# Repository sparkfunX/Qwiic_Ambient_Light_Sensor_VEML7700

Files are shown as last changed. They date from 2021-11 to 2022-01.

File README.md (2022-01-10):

SparkX Ambient Light Sensor - VEML7700 (Qwiic)
========================================

SparkX Ambient Light Sensor - VEML7700 (Qwiic) (SPX-18981) (https://www.sparkfun.com/products/18981)

[*SparkX Ambient Light Sensor - VEML7700 (Qwiic) (SPX-18981)*](https://www.sparkfun.com/products/18981)

The VEML7700 is a high accuracy, 16-bit resolution, digital ambient light sensor in a miniature transparent 6.8 mm x 3.0 mm x 2.5 mm package.
It includes a high sensitivity photodiode, a low noise amplifier, a 16-bit A/D converter and supports an easy to use I<sup>2</sup>C bus communication interface.

* Filtron<sup>TM</sup> technology adaption: close to real human eye response
* O-Trim<sup>TM</sup> technology adoption: ALS output tolerance ≤ 10 %
* 16-bit dynamic range for ambient light detection from 0 lx to about 167 klx with resolution down to 0.005 lx/count
* 100 Hz and 120 Hz flicker noise rejection
* Excellent temperature compensation
* High dynamic detection resolution
* Software shutdown mode control
* High and low threshold windows with interrupt flags

Our [Arduino Library](https://github.com/sparkfun/SparkFun_VEML7700_Arduino_Library) converts the raw sensor data into lux,
automatically compensating for the sensor's gain and integration time settings.

Repository Contents
-------------------

- [**/Documents**](./Documents) - datasheets etc.
- [**/Hardware**](./Hardware) - Eagle PCB, SCH and LBR design files
- [**LICENSE.md**](./LICENSE.md) - contains the licence information

Documentation
--------------

* **[SparkFun VEML7700 Arduino Library](https://github.com/sparkfun/SparkFun_VEML7700_Arduino_Library)** - Arduino library for the ambient light sensor - VEML7700.

Product Versions
----------------

* [SPX-18981](https://www.sparkfun.com/products/18981) - Original SparkX Release.

License Information
-------------------

This product is _**open source**_!

Please review the LICENSE.md file for license information.

If you have any questions or concerns on licensing, please contact technical support on our [SparkFun forums](https://forum.sparkfun.com/viewforum.php?f=152).

Distributed as-is; no warranty is given.

- Your friends at SparkFun.

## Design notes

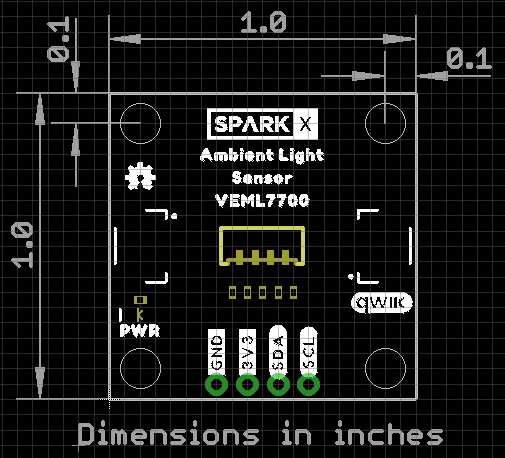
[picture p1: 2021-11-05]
Hardware/Dimensions.jpg

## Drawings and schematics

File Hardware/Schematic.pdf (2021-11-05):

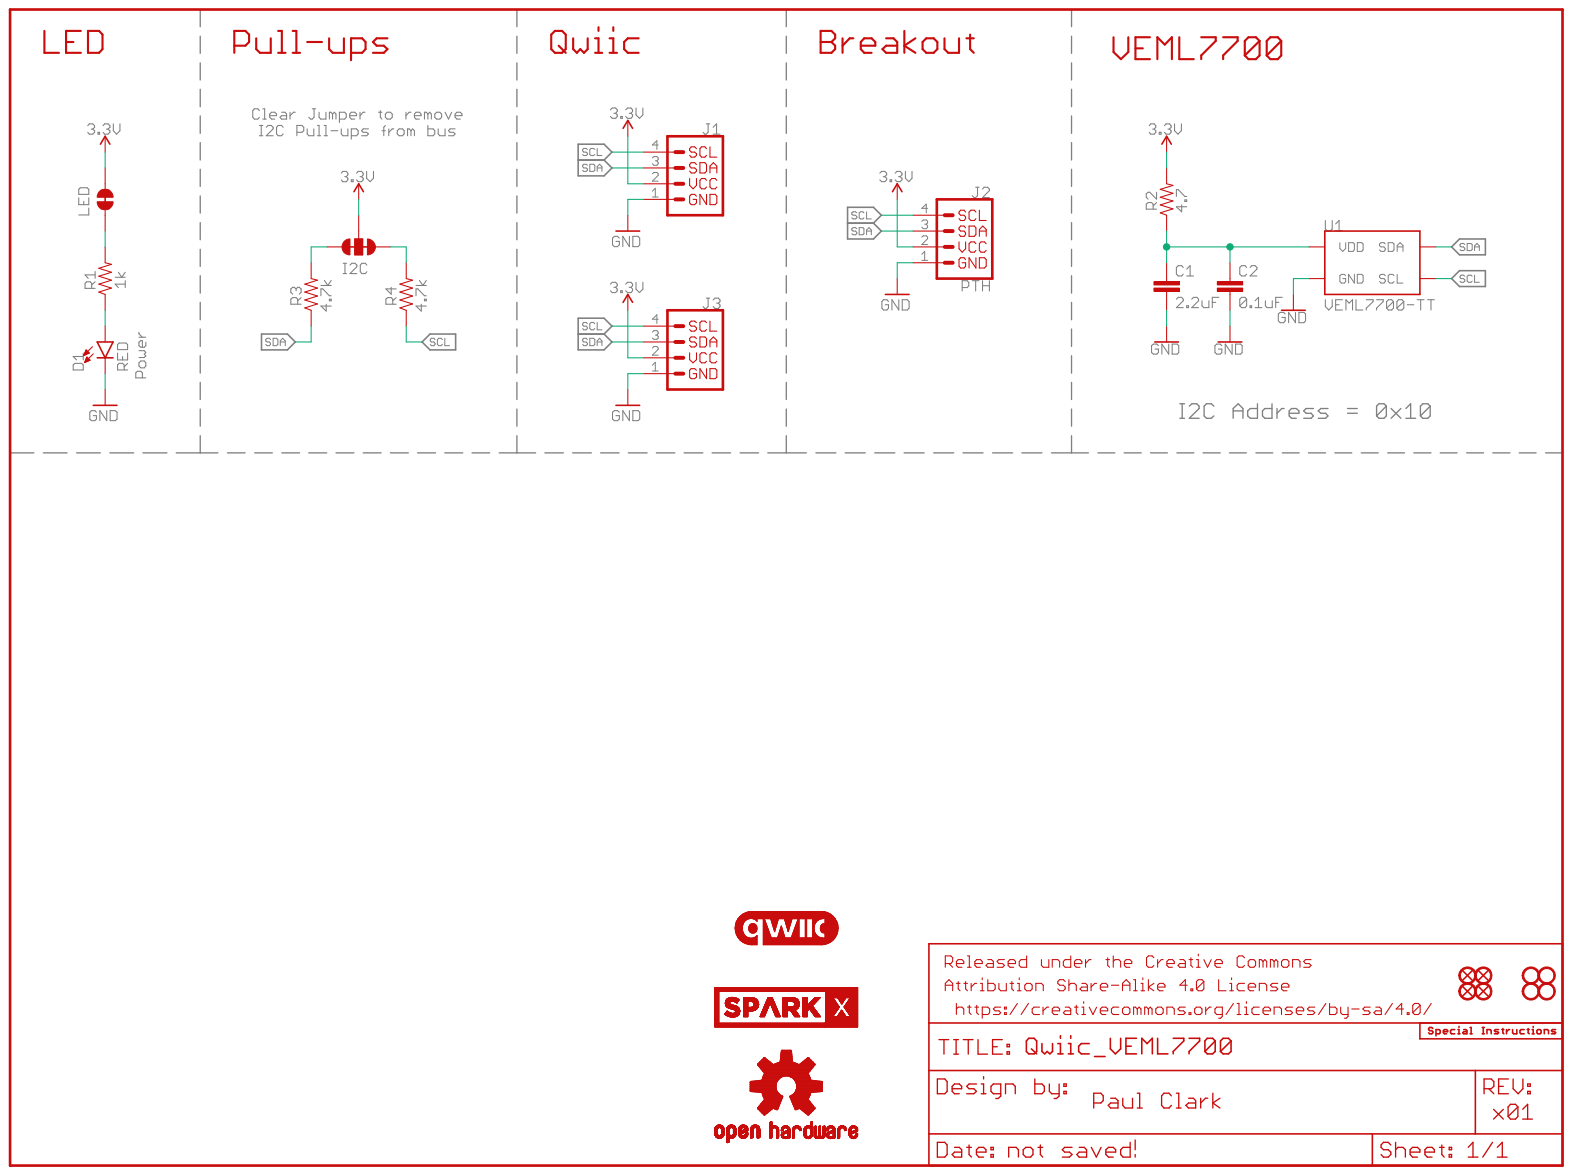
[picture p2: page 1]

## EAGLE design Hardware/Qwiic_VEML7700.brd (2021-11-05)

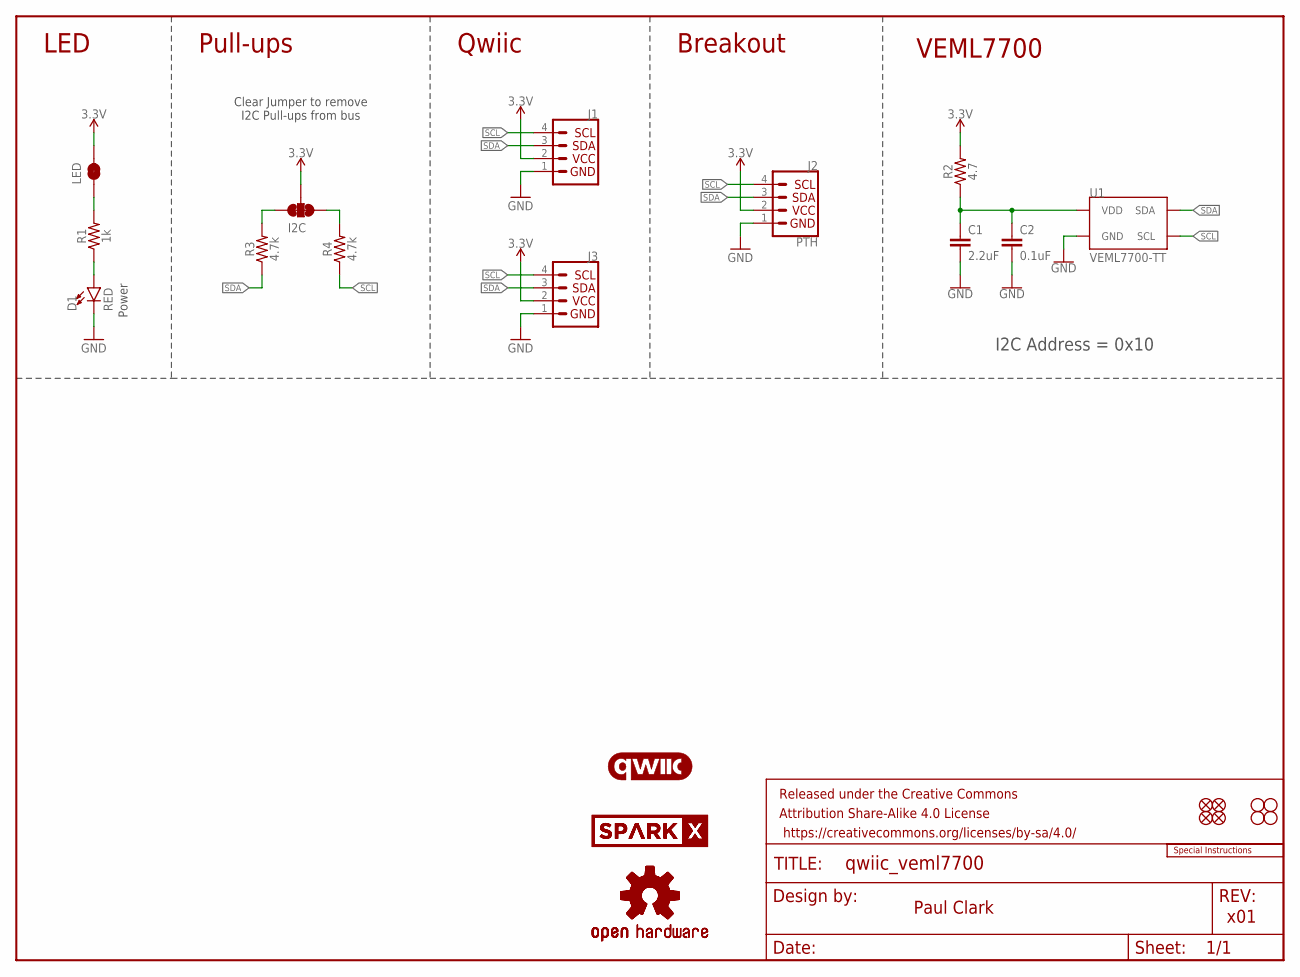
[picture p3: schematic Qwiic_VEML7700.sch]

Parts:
C1: 2.2uF; 0402-TIGHT
C2: 0.1uF; 0402-TIGHT
D1: RED; LED-0603
FRAME1: FRAME-LETTER; CREATIVE_COMMONS
I2C: JUMPER-SMT_3_2-NC_TRACE_SILK; SMT-JUMPER_3_2-NC_TRACE_SILK
J1, J3: Qwiic Right Angle; JST04_1MM_RA
J2: PTH; 1X04_NO_SILK
JP1, JP2, JP5, JP6: FIDUCIAL1X2; FIDUCIAL-1X2
JP3, JP4, JP7, JP8: STAND-OFF
LED: JUMPER-SMT_2_NC_TRACE_SILK; SMT-JUMPER_2_NC_TRACE_SILK
LOGO1, LOGO4: OSHW-LOGOMINI; OSHW-LOGO-MINI
LOGO2: SPECIAL_INSTRUCTIONS-ORDERING; ORDERING_INSTRUCTIONS
LOGO3: QWIIC_LOGO_5MM; QWIIC_5MM
R1: 1k; 0402-TIGHT
R2: 4.7; 0402-TIGHT
R3, R4: 4.7k; 0402-TIGHT
U1: VEML7700-TT; VEML7700_TT
U$2, U$21: SPARKX-LOGO4; SPARKX-MEDIUM

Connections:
3.3V: I2C.2, J1.2, J2.2, J3.2, LED.2, R2.2
GND: C1.2, C2.2, D1.C, J1.1, J2.1, J3.1, U1.3 (GND)
unnamed: I2C.1, R4.2
unnamed: I2C.3, R3.2
unnamed: D1.A, R1.1
unnamed: LED.1, R1.2
unnamed: C1.1, C2.1, R2.1, U1.2 (VDD)
SCL: J1.4, J2.4, J3.4, R4.1, U1.1 (SCL)
SDA: J1.3, J2.3, J3.3, R3.1, U1.4 (SDA)

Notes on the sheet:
Paul Clark
x01
Clear Jumper to remove I2C Pull-ups from bus
Power
LED
Pull-ups
Qwiic
Breakout
VEML7700
I2C Address = 0x10

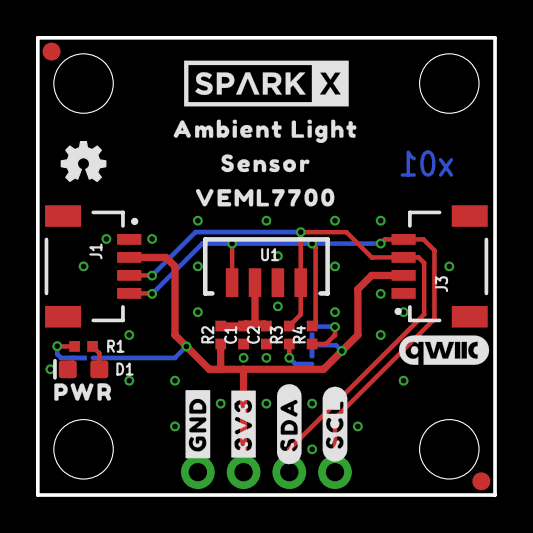
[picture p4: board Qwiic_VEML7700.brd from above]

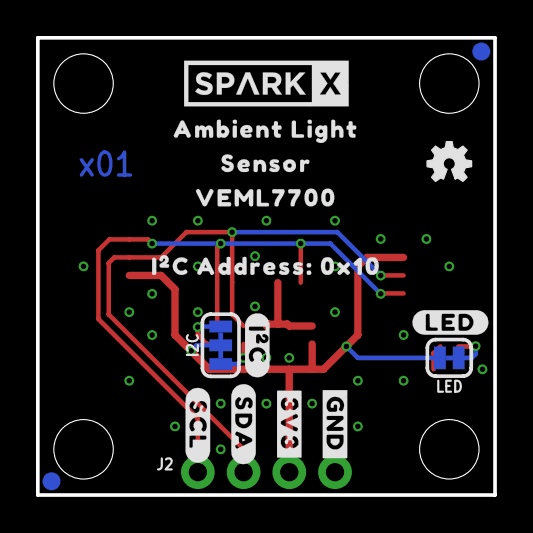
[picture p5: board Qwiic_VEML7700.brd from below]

Board: 2 copper layers, 25.4 x 25.4 mm, 46 parts (17 on the bottom side), 9 nets.

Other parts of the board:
U$1, U$3: #3V3#0
U$4, U$5: #GND#0
U$6, U$7: #SDA#0
U$8, U$9: #SCL#0
U$10: PWR0
U$11, U$12: AMBIENT_LIGHT0
U$13, U$14: SENSOR0
U$15, U$16: VEML77000
U$17: #I�C#0
U$18: I�C_ADDRESS#_0X100
U$19: #LED#0

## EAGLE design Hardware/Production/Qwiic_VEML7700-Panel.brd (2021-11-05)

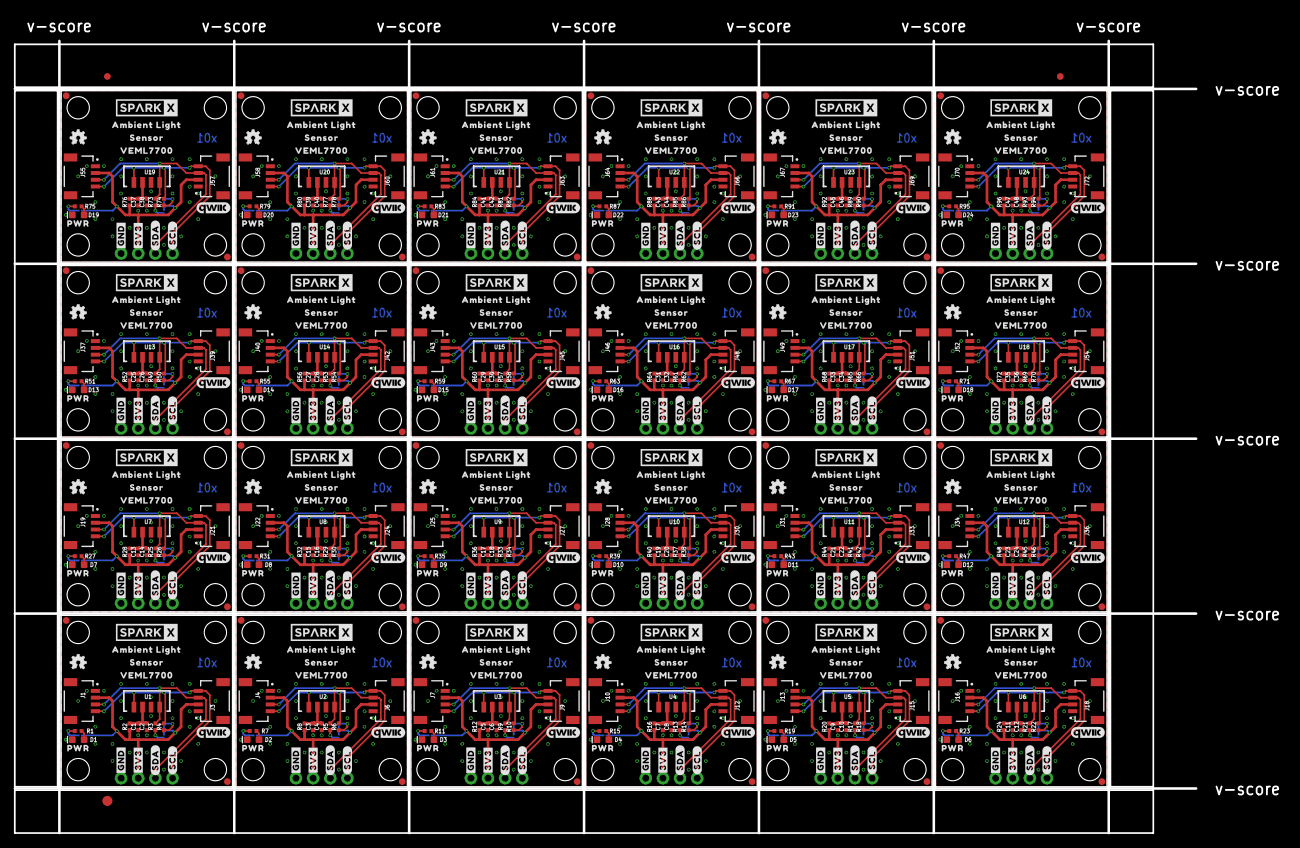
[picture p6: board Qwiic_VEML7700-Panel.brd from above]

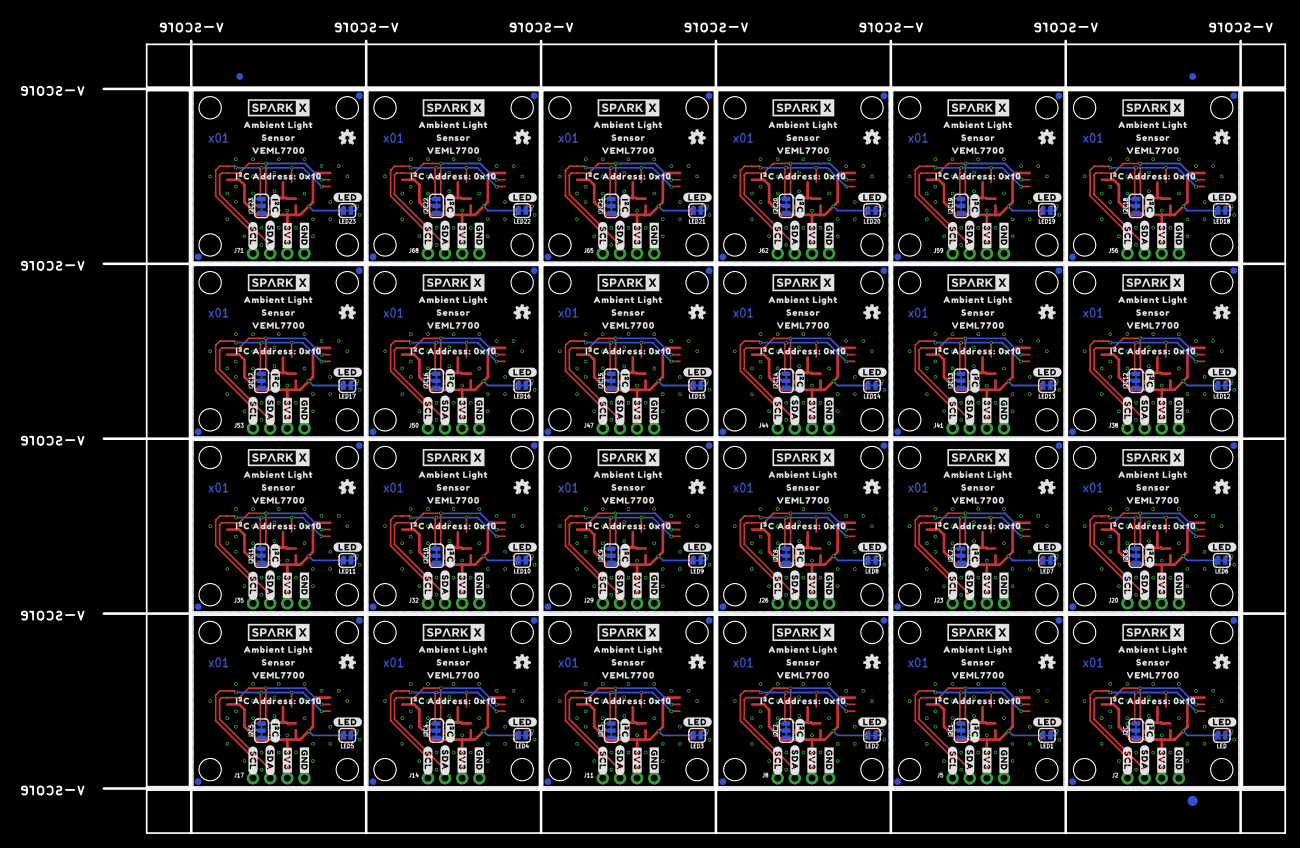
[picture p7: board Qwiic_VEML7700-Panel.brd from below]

Board: 2 copper layers, 175.0 x 117.3 mm, 1062 parts (411 on the bottom side), 216 nets.

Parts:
C1, C3, C5, C7, C9, C11, C13, C15, C17, C19, C21, C23, C25, C27, C29, C31, C33, C35, C37, C39, C41, C43, C45, C47: 2.2uF; 0402-TIGHT
C2, C4, C6, C8, C10, C12, C14, C16, C18, C20, C22, C24, C26, C28, C30, C32, C34, C36, C38, C40, C42, C44, C46, C48: 0.1uF; 0402-TIGHT
D1, D2, D3, D4, D5, D6, D7, D8, D9, D10, D11, D12, D13, D14, D15, D16, D17, D18, D19, D20, D21, D22, D23, D24: RED; LED-0603
E$1, E$2, E$3, E$4: FIDUCIAL-1X2
E$5, E$6: FIDUCIAL-1.5X3
I2C, I2C1, I2C2, I2C3, I2C4, I2C5, I2C6, I2C7, I2C8, I2C9, I2C10, I2C11, I2C12, I2C13, I2C14, I2C15, I2C16, I2C17, I2C18, I2C19, I2C20, I2C21, I2C22, I2C23: JUMPER-SMT_3_2-NC_TRACE_SILK; SMT-JUMPER_3_2-NC_TRACE_SILK
J1, J3, J4, J6, J7, J9, J10, J12, J13, J15, J16, J18, J19, J21, J22, J24, J25, J27, J28, J30, J31, J33, J34, J36, J37, J39, J40, J42, J43, J45, J46, J48, J49, J51, J52, J54, J55, J57, J58, J60, J61, J63, J64, J66, J67, J69, J70, J72: Qwiic Right Angle; JST04_1MM_RA
J2, J5, J8, J11, J14, J17, J20, J23, J26, J29, J32, J35, J38, J41, J44, J47, J50, J53, J56, J59, J62, J65, J68, J71: PTH; 1X04_NO_SILK
JP1, JP2, JP5, JP6, JP11, JP12, JP13, JP14, JP19, JP20, JP21, JP22, JP27, JP28, JP29, JP30, JP35, JP36, JP37, JP38, JP43, JP44, JP45, JP46, JP51, JP52, JP53, JP54, JP59, JP60, JP61, JP62, JP67, JP68, JP69, JP70, JP75, JP76, JP77, JP78, JP83, JP84, JP85, JP86, JP91, JP92, JP93, JP94, JP99, JP100, JP101, JP102, JP107, JP108, JP109, JP110, JP115, JP116, JP117, JP118, JP123, JP124, JP125, JP126, JP131, JP132, JP133, JP134, JP139, JP140, JP141, JP142, JP147, JP148, JP149, JP150, JP155, JP156, JP157, JP158, JP163, JP164, JP165, JP166, JP171, JP172, JP173, JP174, JP179, JP180, JP181, JP182, JP187, JP188, JP189, JP190: FIDUCIAL1X2; FIDUCIAL-1X2
JP3, JP4, JP7, JP8, JP9, JP10, JP15, JP16, JP17, JP18, JP23, JP24, JP25, JP26, JP31, JP32, JP33, JP34, JP39, JP40, JP41, JP42, JP47, JP48, JP49, JP50, JP55, JP56, JP57, JP58, JP63, JP64, JP65, JP66, JP71, JP72, JP73, JP74, JP79, JP80, JP81, JP82, JP87, JP88, JP89, JP90, JP95, JP96, JP97, JP98, JP103, JP104, JP105, JP106, JP111, JP112, JP113, JP114, JP119, JP120, JP121, JP122, JP127, JP128, JP129, JP130, JP135, JP136, JP137, JP138, JP143, JP144, JP145, JP146, JP151, JP152, JP153, JP154, JP159, JP160, JP161, JP162, JP167, JP168, JP169, JP170, JP175, JP176, JP177, JP178, JP183, JP184, JP185, JP186, JP191, JP192: STAND-OFF
LED, LED1, LED2, LED3, LED4, LED5, LED6, LED7, LED8, LED9, LED10, LED11, LED12, LED13, LED14, LED15, LED16, LED17, LED18, LED19, LED20, LED21, LED22, LED23: SMT-JUMPER_2_NC_TRACE_SILK
LOGO1, LOGO2, LOGO4, LOGO6, LOGO7, LOGO9, LOGO10, LOGO12, LOGO13, LOGO15, LOGO16, LOGO18, LOGO19, LOGO21, LOGO22, LOGO24, LOGO25, LOGO27, LOGO28, LOGO30, LOGO31, LOGO33, LOGO34, LOGO36, LOGO37, LOGO39, LOGO40, LOGO42, LOGO43, LOGO45, LOGO46, LOGO48, LOGO49, LOGO51, LOGO52, LOGO54, LOGO55, LOGO57, LOGO58, LOGO60, LOGO61, LOGO63, LOGO64, LOGO66, LOGO67, LOGO69, LOGO70, LOGO72: OSHW-LOGOMINI; OSHW-LOGO-MINI
LOGO3, LOGO5, LOGO8, LOGO11, LOGO14, LOGO17, LOGO20, LOGO23, LOGO26, LOGO29, LOGO32, LOGO35, LOGO38, LOGO41, LOGO44, LOGO47, LOGO50, LOGO53, LOGO56, LOGO59, LOGO62, LOGO65, LOGO68, LOGO71: QWIIC_LOGO_5MM; QWIIC_5MM
R1, R7, R11, R15, R19, R23, R27, R31, R35, R39, R43, R47, R51, R55, R59, R63, R67, R71, R75, R79, R83, R87, R91, R95: 1k; 0402-TIGHT
R2, R8, R12, R16, R20, R24, R28, R32, R36, R40, R44, R48, R52, R56, R60, R64, R68, R72, R76, R80, R84, R88, R92, R96: 4.7; 0402-TIGHT
R3, R4, R5, R6, R9, R10, R13, R14, R17, R18, R21, R22, R25, R26, R29, R30, R33, R34, R37, R38, R41, R42, R45, R46, R49, R50, R53, R54, R57, R58, R61, R62, R65, R66, R69, R70, R73, R74, R77, R78, R81, R82, R85, R86, R89, R90, R93, R94: 4.7k; 0402-TIGHT
U1, U2, U3, U4, U5, U6, U7, U8, U9, U10, U11, U12, U13, U14, U15, U16, U17, U18, U19, U20, U21, U22, U23, U24: VEML7700-TT; VEML7700_TT
U$1, U$3, U$23, U$24, U$43, U$44, U$63, U$64, U$83, U$84, U$103, U$104, U$123, U$124, U$143, U$144, U$163, U$164, U$183, U$184, U$203, U$204, U$223, U$224, U$243, U$244, U$263, U$264, U$283, U$284, U$303, U$304, U$323, U$324, U$343, U$344, U$363, U$364, U$383, U$384, U$403, U$404, U$423, U$424, U$443, U$444, U$463, U$464: #3V3#0
U$2, U$20, U$21, U$22, U$41, U$42, U$61, U$62, U$81, U$82, U$101, U$102, U$121, U$122, U$141, U$142, U$161, U$162, U$181, U$182, U$201, U$202, U$221, U$222, U$241, U$242, U$261, U$262, U$281, U$282, U$301, U$302, U$321, U$322, U$341, U$342, U$361, U$362, U$381, U$382, U$401, U$402, U$421, U$422, U$441, U$442, U$461, U$462: SPARKX-LOGO4; SPARKX-MEDIUM
U$4, U$5, U$25, U$26, U$45, U$46, U$65, U$66, U$85, U$86, U$105, U$106, U$125, U$126, U$145, U$146, U$165, U$166, U$185, U$186, U$205, U$206, U$225, U$226, U$245, U$246, U$265, U$266, U$285, U$286, U$305, U$306, U$325, U$326, U$345, U$346, U$365, U$366, U$385, U$386, U$405, U$406, U$425, U$426, U$445, U$446, U$465, U$466: #GND#0
U$6, U$7, U$27, U$28, U$47, U$48, U$67, U$68, U$87, U$88, U$107, U$108, U$127, U$128, U$147, U$148, U$167, U$168, U$187, U$188, U$207, U$208, U$227, U$228, U$247, U$248, U$267, U$268, U$287, U$288, U$307, U$308, U$327, U$328, U$347, U$348, U$367, U$368, U$387, U$388, U$407, U$408, U$427, U$428, U$447, U$448, U$467, U$468: #SDA#0
U$8, U$9, U$29, U$30, U$49, U$50, U$69, U$70, U$89, U$90, U$109, U$110, U$129, U$130, U$149, U$150, U$169, U$170, U$189, U$190, U$209, U$210, U$229, U$230, U$249, U$250, U$269, U$270, U$289, U$290, U$309, U$310, U$329, U$330, U$349, U$350, U$369, U$370, U$389, U$390, U$409, U$410, U$429, U$430, U$449, U$450, U$469, U$470: #SCL#0
U$10, U$31, U$51, U$71, U$91, U$111, U$131, U$151, U$171, U$191, U$211, U$231, U$251, U$271, U$291, U$311, U$331, U$351, U$371, U$391, U$411, U$431, U$451, U$471: PWR0
U$11, U$12, U$32, U$33, U$52, U$53, U$72, U$73, U$92, U$93, U$112, U$113, U$132, U$133, U$152, U$153, U$172, U$173, U$192, U$193, U$212, U$213, U$232, U$233, U$252, U$253, U$272, U$273, U$292, U$293, U$312, U$313, U$332, U$333, U$352, U$353, U$372, U$373, U$392, U$393, U$412, U$413, U$432, U$433, U$452, U$453, U$472, U$473: AMBIENT_LIGHT0
U$13, U$14, U$34, U$35, U$54, U$55, U$74, U$75, U$94, U$95, U$114, U$115, U$134, U$135, U$154, U$155, U$174, U$175, U$194, U$195, U$214, U$215, U$234, U$235, U$254, U$255, U$274, U$275, U$294, U$295, U$314, U$315, U$334, U$335, U$354, U$355, U$374, U$375, U$394, U$395, U$414, U$415, U$434, U$435, U$454, U$455, U$474, U$475: SENSOR0
U$15, U$16, U$36, U$37, U$56, U$57, U$76, U$77, U$96, U$97, U$116, U$117, U$136, U$137, U$156, U$157, U$176, U$177, U$196, U$197, U$216, U$217, U$236, U$237, U$256, U$257, U$276, U$277, U$296, U$297, U$316, U$317, U$336, U$337, U$356, U$357, U$376, U$377, U$396, U$397, U$416, U$417, U$436, U$437, U$456, U$457, U$476, U$477: VEML77000
U$17, U$38, U$58, U$78, U$98, U$118, U$138, U$158, U$178, U$198, U$218, U$238, U$258, U$278, U$298, U$318, U$338, U$358, U$378, U$398, U$418, U$438, U$458, U$478: #I�C#0
U$18, U$39, U$59, U$79, U$99, U$119, U$139, U$159, U$179, U$199, U$219, U$239, U$259, U$279, U$299, U$319, U$339, U$359, U$379, U$399, U$419, U$439, U$459, U$479: I�C_ADDRESS#_0X100
U$19, U$40, U$60, U$80, U$100, U$120, U$140, U$160, U$180, U$200, U$220, U$240, U$260, U$280, U$300, U$320, U$340, U$360, U$380, U$400, U$420, U$440, U$460, U$480: #LED#0

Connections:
3.3V: I2C.2, J1.2, J2.2, J3.2, LED.2, R2.2
3.3V1: I2C1.2, J4.2, J5.2, J6.2, LED1.2, R8.2
3.3V2: I2C2.2, J7.2, J8.2, J9.2, LED2.2, R12.2
3.3V3: I2C3.2, J10.2, J11.2, J12.2, LED3.2, R16.2
3.3V4: I2C4.2, J13.2, J14.2, J15.2, LED4.2, R20.2
3.3V5: I2C5.2, J16.2, J17.2, J18.2, LED5.2, R24.2
3.3V6: I2C6.2, J19.2, J20.2, J21.2, LED6.2, R28.2
3.3V7: I2C7.2, J22.2, J23.2, J24.2, LED7.2, R32.2
3.3V8: I2C8.2, J25.2, J26.2, J27.2, LED8.2, R36.2
3.3V9: I2C9.2, J28.2, J29.2, J30.2, LED9.2, R40.2
3.3V10: I2C10.2, J31.2, J32.2, J33.2, LED10.2, R44.2
3.3V11: I2C11.2, J34.2, J35.2, J36.2, LED11.2, R48.2
3.3V12: I2C12.2, J37.2, J38.2, J39.2, LED12.2, R52.2
3.3V13: I2C13.2, J40.2, J41.2, J42.2, LED13.2, R56.2
3.3V14: I2C14.2, J43.2, J44.2, J45.2, LED14.2, R60.2
3.3V15: I2C15.2, J46.2, J47.2, J48.2, LED15.2, R64.2
3.3V16: I2C16.2, J49.2, J50.2, J51.2, LED16.2, R68.2
3.3V17: I2C17.2, J52.2, J53.2, J54.2, LED17.2, R72.2
3.3V18: I2C18.2, J55.2, J56.2, J57.2, LED18.2, R76.2
3.3V19: I2C19.2, J58.2, J59.2, J60.2, LED19.2, R80.2
3.3V20: I2C20.2, J61.2, J62.2, J63.2, LED20.2, R84.2
3.3V21: I2C21.2, J64.2, J65.2, J66.2, LED21.2, R88.2
3.3V22: I2C22.2, J67.2, J68.2, J69.2, LED22.2, R92.2
3.3V23: I2C23.2, J70.2, J71.2, J72.2, LED23.2, R96.2
GND: C1.2, C2.2, D1.C, J1.1, J2.1, J3.1, U1.3
GND1: C3.2, C4.2, D2.C, J4.1, J5.1, J6.1, U2.3
GND2: C5.2, C6.2, D3.C, J7.1, J8.1, J9.1, U3.3
GND3: C7.2, C8.2, D4.C, J10.1, J11.1, J12.1, U4.3
GND4: C9.2, C10.2, D5.C, J13.1, J14.1, J15.1, U5.3
GND5: C11.2, C12.2, D6.C, J16.1, J17.1, J18.1, U6.3
GND6: C13.2, C14.2, D7.C, J19.1, J20.1, J21.1, U7.3
GND7: C15.2, C16.2, D8.C, J22.1, J23.1, J24.1, U8.3
GND8: C17.2, C18.2, D9.C, J25.1, J26.1, J27.1, U9.3
GND9: C19.2, C20.2, D10.C, J28.1, J29.1, J30.1, U10.3
GND10: C21.2, C22.2, D11.C, J31.1, J32.1, J33.1, U11.3
GND11: C23.2, C24.2, D12.C, J34.1, J35.1, J36.1, U12.3
GND12: C25.2, C26.2, D13.C, J37.1, J38.1, J39.1, U13.3
GND13: C27.2, C28.2, D14.C, J40.1, J41.1, J42.1, U14.3
GND14: C29.2, C30.2, D15.C, J43.1, J44.1, J45.1, U15.3
GND15: C31.2, C32.2, D16.C, J46.1, J47.1, J48.1, U16.3
GND16: C33.2, C34.2, D17.C, J49.1, J50.1, J51.1, U17.3
GND17: C35.2, C36.2, D18.C, J52.1, J53.1, J54.1, U18.3
GND18: C37.2, C38.2, D19.C, J55.1, J56.1, J57.1, U19.3
GND19: C39.2, C40.2, D20.C, J58.1, J59.1, J60.1, U20.3
GND20: C41.2, C42.2, D21.C, J61.1, J62.1, J63.1, U21.3
GND21: C43.2, C44.2, D22.C, J64.1, J65.1, J66.1, U22.3
GND22: C45.2, C46.2, D23.C, J67.1, J68.1, J69.1, U23.3
GND23: C47.2, C48.2, D24.C, J70.1, J71.1, J72.1, U24.3
unnamed: I2C.1, R4.2
unnamed: I2C.3, R3.2
unnamed: D1.A, R1.1
unnamed: LED.1, R1.2
unnamed: C1.1, C2.1, R2.1, U1.2
unnamed: I2C1.1, R6.2
unnamed: I2C1.3, R5.2
unnamed: D2.A, R7.1
unnamed: LED1.1, R7.2
unnamed: C3.1, C4.1, R8.1, U2.2
unnamed: I2C2.1, R10.2
unnamed: I2C2.3, R9.2
unnamed: D3.A, R11.1
unnamed: LED2.1, R11.2
unnamed: C5.1, C6.1, R12.1, U3.2
unnamed: I2C3.1, R14.2
unnamed: I2C3.3, R13.2
unnamed: D4.A, R15.1
unnamed: LED3.1, R15.2
unnamed: C7.1, C8.1, R16.1, U4.2
unnamed: I2C4.1, R18.2
unnamed: I2C4.3, R17.2
unnamed: D5.A, R19.1
unnamed: LED4.1, R19.2
unnamed: C9.1, C10.1, R20.1, U5.2
unnamed: I2C5.1, R22.2
unnamed: I2C5.3, R21.2
unnamed: D6.A, R23.1
unnamed: LED5.1, R23.2
unnamed: C11.1, C12.1, R24.1, U6.2
unnamed: I2C6.1, R26.2
unnamed: I2C6.3, R25.2
unnamed: D7.A, R27.1
unnamed: LED6.1, R27.2
unnamed: C13.1, C14.1, R28.1, U7.2
unnamed: I2C7.1, R30.2
unnamed: I2C7.3, R29.2
unnamed: D8.A, R31.1
unnamed: LED7.1, R31.2
unnamed: C15.1, C16.1, R32.1, U8.2
unnamed: I2C8.1, R34.2
unnamed: I2C8.3, R33.2
unnamed: D9.A, R35.1
unnamed: LED8.1, R35.2
unnamed: C17.1, C18.1, R36.1, U9.2
unnamed: I2C9.1, R38.2
unnamed: I2C9.3, R37.2
unnamed: D10.A, R39.1
unnamed: LED9.1, R39.2
unnamed: C19.1, C20.1, R40.1, U10.2
unnamed: I2C10.1, R42.2
unnamed: I2C10.3, R41.2
unnamed: D11.A, R43.1
unnamed: LED10.1, R43.2
unnamed: C21.1, C22.1, R44.1, U11.2
unnamed: I2C11.1, R46.2
unnamed: I2C11.3, R45.2
unnamed: D12.A, R47.1
unnamed: LED11.1, R47.2
unnamed: C23.1, C24.1, R48.1, U12.2
unnamed: I2C12.1, R50.2
unnamed: I2C12.3, R49.2
unnamed: D13.A, R51.1
unnamed: LED12.1, R51.2
unnamed: C25.1, C26.1, R52.1, U13.2
unnamed: I2C13.1, R54.2
unnamed: I2C13.3, R53.2
unnamed: D14.A, R55.1
unnamed: LED13.1, R55.2
unnamed: C27.1, C28.1, R56.1, U14.2
unnamed: I2C14.1, R58.2
unnamed: I2C14.3, R57.2
unnamed: D15.A, R59.1
unnamed: LED14.1, R59.2
unnamed: C29.1, C30.1, R60.1, U15.2
unnamed: I2C15.1, R62.2
unnamed: I2C15.3, R61.2
unnamed: D16.A, R63.1
unnamed: LED15.1, R63.2
unnamed: C31.1, C32.1, R64.1, U16.2
unnamed: I2C16.1, R66.2
unnamed: I2C16.3, R65.2
unnamed: D17.A, R67.1
unnamed: LED16.1, R67.2
unnamed: C33.1, C34.1, R68.1, U17.2
unnamed: I2C17.1, R70.2
unnamed: I2C17.3, R69.2
unnamed: D18.A, R71.1
unnamed: LED17.1, R71.2
unnamed: C35.1, C36.1, R72.1, U18.2
unnamed: I2C18.1, R74.2
unnamed: I2C18.3, R73.2
unnamed: D19.A, R75.1
unnamed: LED18.1, R75.2
unnamed: C37.1, C38.1, R76.1, U19.2
unnamed: I2C19.1, R78.2
unnamed: I2C19.3, R77.2
unnamed: D20.A, R79.1
unnamed: LED19.1, R79.2
unnamed: C39.1, C40.1, R80.1, U20.2
unnamed: I2C20.1, R82.2
unnamed: I2C20.3, R81.2
unnamed: D21.A, R83.1
unnamed: LED20.1, R83.2
unnamed: C41.1, C42.1, R84.1, U21.2
unnamed: I2C21.1, R86.2
unnamed: I2C21.3, R85.2
unnamed: D22.A, R87.1
unnamed: LED21.1, R87.2
unnamed: C43.1, C44.1, R88.1, U22.2
unnamed: I2C22.1, R90.2
unnamed: I2C22.3, R89.2
unnamed: D23.A, R91.1
unnamed: LED22.1, R91.2
unnamed: C45.1, C46.1, R92.1, U23.2
unnamed: I2C23.1, R94.2
unnamed: I2C23.3, R93.2
unnamed: D24.A, R95.1
unnamed: LED23.1, R95.2
unnamed: C47.1, C48.1, R96.1, U24.2
SCL: J1.4, J2.4, J3.4, R4.1, U1.1
SCL1: J4.4, J5.4, J6.4, R6.1, U2.1
SCL2: J7.4, J8.4, J9.4, R10.1, U3.1
SCL3: J10.4, J11.4, J12.4, R14.1, U4.1
SCL4: J13.4, J14.4, J15.4, R18.1, U5.1
SCL5: J16.4, J17.4, J18.4, R22.1, U6.1
SCL6: J19.4, J20.4, J21.4, R26.1, U7.1
SCL7: J22.4, J23.4, J24.4, R30.1, U8.1
SCL8: J25.4, J26.4, J27.4, R34.1, U9.1
SCL9: J28.4, J29.4, J30.4, R38.1, U10.1
SCL10: J31.4, J32.4, J33.4, R42.1, U11.1
SCL11: J34.4, J35.4, J36.4, R46.1, U12.1
SCL12: J37.4, J38.4, J39.4, R50.1, U13.1
SCL13: J40.4, J41.4, J42.4, R54.1, U14.1
SCL14: J43.4, J44.4, J45.4, R58.1, U15.1
SCL15: J46.4, J47.4, J48.4, R62.1, U16.1
SCL16: J49.4, J50.4, J51.4, R66.1, U17.1
SCL17: J52.4, J53.4, J54.4, R70.1, U18.1
SCL18: J55.4, J56.4, J57.4, R74.1, U19.1
SCL19: J58.4, J59.4, J60.4, R78.1, U20.1
SCL20: J61.4, J62.4, J63.4, R82.1, U21.1
SCL21: J64.4, J65.4, J66.4, R86.1, U22.1
SCL22: J67.4, J68.4, J69.4, R90.1, U23.1
SCL23: J70.4, J71.4, J72.4, R94.1, U24.1
SDA: J1.3, J2.3, J3.3, R3.1, U1.4
SDA1: J4.3, J5.3, J6.3, R5.1, U2.4
SDA2: J7.3, J8.3, J9.3, R9.1, U3.4
SDA3: J10.3, J11.3, J12.3, R13.1, U4.4
SDA4: J13.3, J14.3, J15.3, R17.1, U5.4
SDA5: J16.3, J17.3, J18.3, R21.1, U6.4
SDA6: J19.3, J20.3, J21.3, R25.1, U7.4
SDA7: J22.3, J23.3, J24.3, R29.1, U8.4
SDA8: J25.3, J26.3, J27.3, R33.1, U9.4
SDA9: J28.3, J29.3, J30.3, R37.1, U10.4
SDA10: J31.3, J32.3, J33.3, R41.1, U11.4
SDA11: J34.3, J35.3, J36.3, R45.1, U12.4
SDA12: J37.3, J38.3, J39.3, R49.1, U13.4
SDA13: J40.3, J41.3, J42.3, R53.1, U14.4
SDA14: J43.3, J44.3, J45.3, R57.1, U15.4
SDA15: J46.3, J47.3, J48.3, R61.1, U16.4
SDA16: J49.3, J50.3, J51.3, R65.1, U17.4
SDA17: J52.3, J53.3, J54.3, R69.1, U18.4
SDA18: J55.3, J56.3, J57.3, R73.1, U19.4
SDA19: J58.3, J59.3, J60.3, R77.1, U20.4
SDA20: J61.3, J62.3, J63.3, R81.1, U21.4
SDA21: J64.3, J65.3, J66.3, R85.1, U22.4
SDA22: J67.3, J68.3, J69.3, R89.1, U23.4
SDA23: J70.3, J71.3, J72.3, R93.1, U24.4

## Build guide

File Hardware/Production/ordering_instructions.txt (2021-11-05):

panel size, 169x117mm
PCB thickness, 1.6mm
number of layers, 2
soldermask color, Black
silkscreen color, White
oz copper, 1oz
finish, HASL lead free
stencils, top
pcs per panel, 24
min trace width, 0.2540mm / 0.0100in
min drill size, 0.3000mm / 0.0118in

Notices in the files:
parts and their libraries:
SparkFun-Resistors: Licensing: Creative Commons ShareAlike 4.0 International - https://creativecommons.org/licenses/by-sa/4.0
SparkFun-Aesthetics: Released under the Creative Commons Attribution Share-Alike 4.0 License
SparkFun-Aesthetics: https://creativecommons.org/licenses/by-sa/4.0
